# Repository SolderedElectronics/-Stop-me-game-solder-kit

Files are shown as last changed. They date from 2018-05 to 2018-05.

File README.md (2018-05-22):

# DIY_Stop_Me_Game_Kit

# Description and details
"Stop Me" game is small and simple game running on ATtiny13 microcontroller. It consists of 7 LEDs, push button, small CR2032 battery and microcontroller. The game starts with LEDs lightning up in sequential order. LED in the middle (4th in row) is different color in comparison to the rest of the LEDs. Goal of the game is very simple, player must press the push button when the middle LED (only one in different color) is light up. If the correct LED is turned on when the push button is pressed, the player goes on next level where time delay between LED lighting up is shortened. If any other LED is turned on when the push button is pressed, the game restarts to the first level. The game is designed to have multiple levels (12 in total). 

This game is designed as a DIY soldering kit. This kit is ideal for kids and soldering beginners who can exercise their skills with this simple & easy game. While learning to solder, you will also create unique gadget which you can carry around. In addition, while playing this simple game, players can exercise their reflex skills.

# Repository content

This repo is divided into two parts: Eagle Files and Firmware. Eagle Files folder contains Cadsoft Eagle .sch and .brd files for "Stop Me" game PCB board. in addition there is schematic in .pdf created from .sch eagle file. In Firmware folder you can find C code for programming ATtiny13 microcontroller. The entire program code uses less than 1kB of Flash memory.

# Instructions on soldering

1. Insert the 8 pin IC socket into IC. Flip the board over, then solder into place.
2. Insert the switch and pushbutton into S1 and S2. Flip the board over and solder into place.
3. Insert 7 LEDs into LED1, LED2, LED2, LED3, LED4, LED5, LED6. Each LED has a short leg and a long leg. The long leg goes into the hole closest to the "+" sign on the board. NOTE: The green LED goes into LED4 place. Flip the board over, then solder into place.
4. Flip the board over. Put CR2032 battery holder into BAT place. Don't put battery in holder just yet. Flip the board over again and solder into place. The battery holder is only piece which is soldered on the back side of PCB.
5. Insert Attiny13 microcontroller into 8 pin IC socket. Make sure the dot in the corner of the chip is on bottom left corner.
6. Insert CR2032 battery into soldered battery holder.
7. Yay you're done! Flip the switch to the ON position and the game should start. Have Fun playing it. 

# Board versions
- v1.0 - initial version

# License info
This product is open-source. YAY!

e-radionica.com Team.

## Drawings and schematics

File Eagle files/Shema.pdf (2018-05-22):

A

B

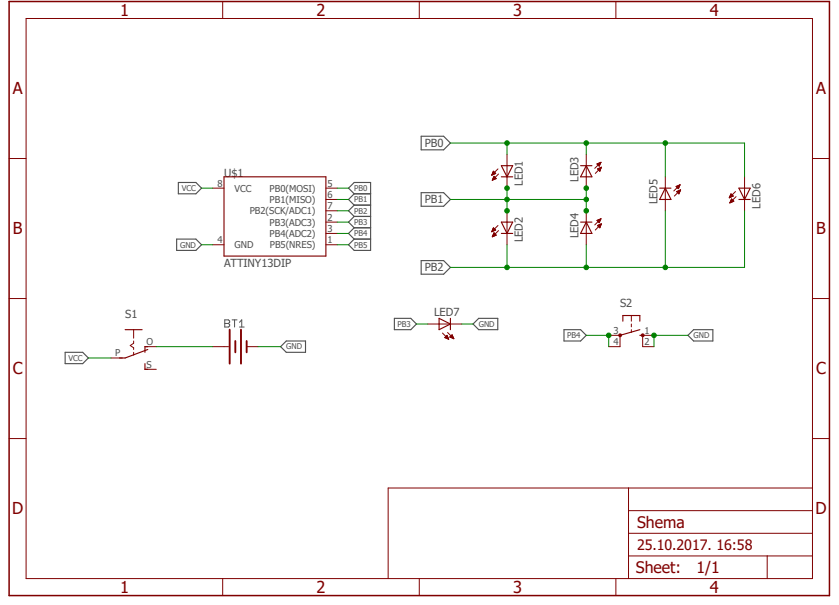
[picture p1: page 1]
ATTINY13DIP; U$1 VCC 8; PB1(MISO); PB5(NRES); 1 GND 4; PB0(MOSI); PB2(SCK/ADC1); PB3(ADC3); PB4(ADC2); LED¹ LED²; LED³ LED⁴; LED⁵; LED⁶; LED7; VCC; GND; Shema; 25.10.2017. 16:58 Sheet: 1/1

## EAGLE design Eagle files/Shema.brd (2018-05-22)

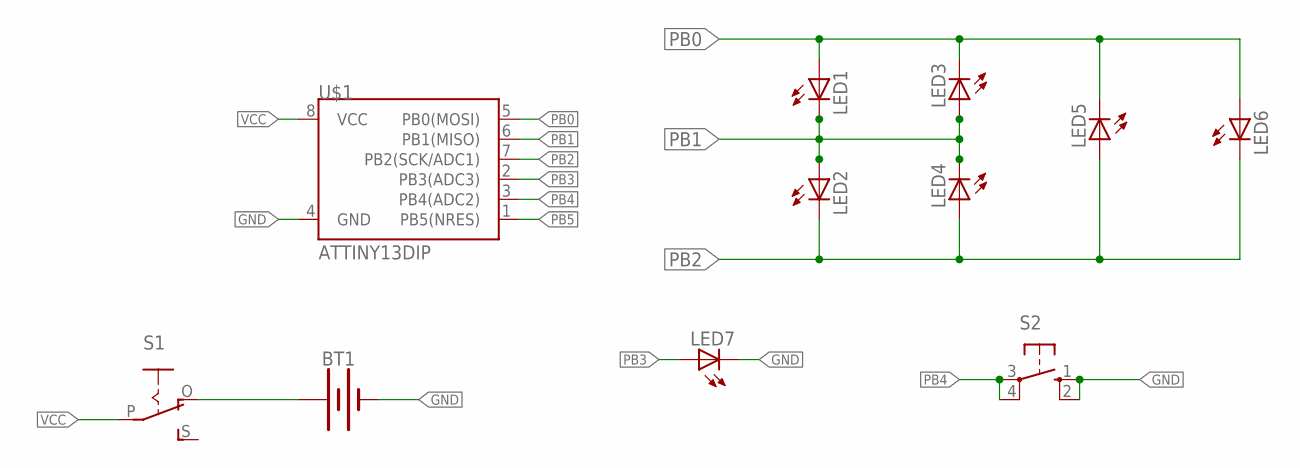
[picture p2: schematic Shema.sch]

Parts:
BT1: BATTERY-20MM_PTH; BATTCOM_20MM_PTH
LED1, LED2, LED3, LED4, LED5, LED6, LED7: LED5MM
S1: EG1218S; EG1218
S2: 40-XX; B3F-40XX
U$1: ATTINY13DIP; DIP08_MCU

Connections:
GND: BT1.2 (-), LED7.K (C), S2.1 (S), S2.2 (S1), U$1.4 (GND)
unnamed: BT1.1 (+), S1.O
PB0: LED1.A, LED3.K (C), LED5.K (C), LED6.A, U$1.5 (PB0(MOSI))
PB1: LED1.K (C), LED2.A, LED3.A, LED4.K (C), U$1.6 (PB1(MISO))
PB2: LED2.K (C), LED4.A, LED5.A, LED6.K (C), U$1.7 (PB2(SCK/ADC1))
PB3: LED7.A, U$1.2 (PB3(ADC3))
PB4: S2.3, S2.4 (P1), U$1.3 (PB4(ADC2))
PB5: U$1.1 (PB5(NRES))
VCC: S1.P, U$1.8 (VCC)

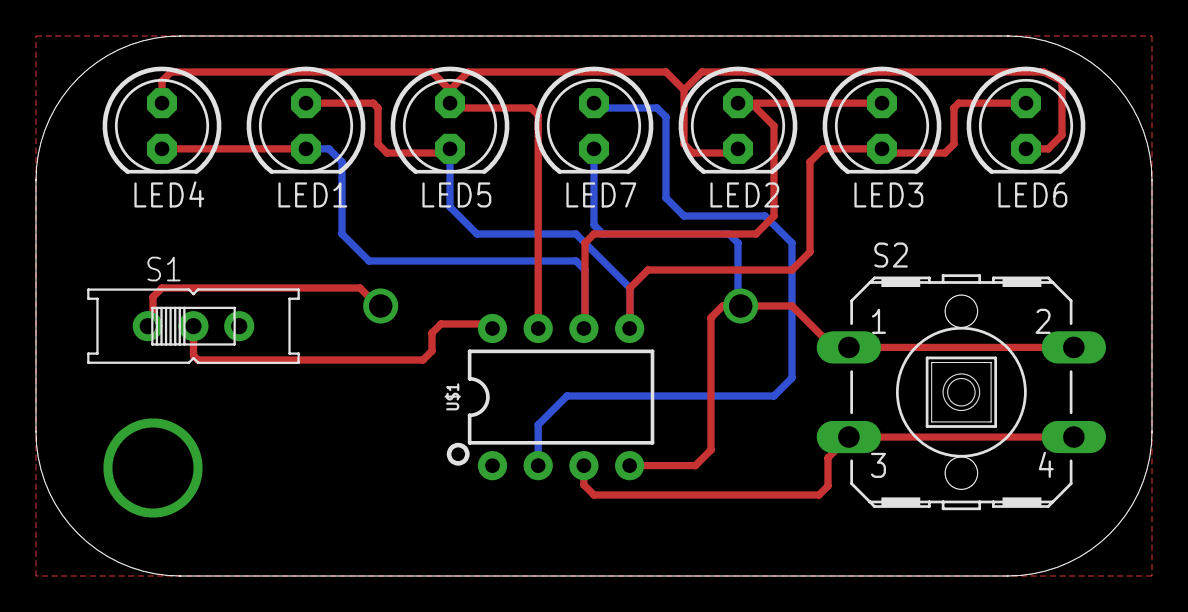
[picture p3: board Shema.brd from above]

Board: 2 copper layers, 62.0 x 30.0 mm, 11 parts (1 on the bottom side), 8 nets.

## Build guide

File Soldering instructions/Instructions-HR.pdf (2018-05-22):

### DIY „STOP ME“ IGRA

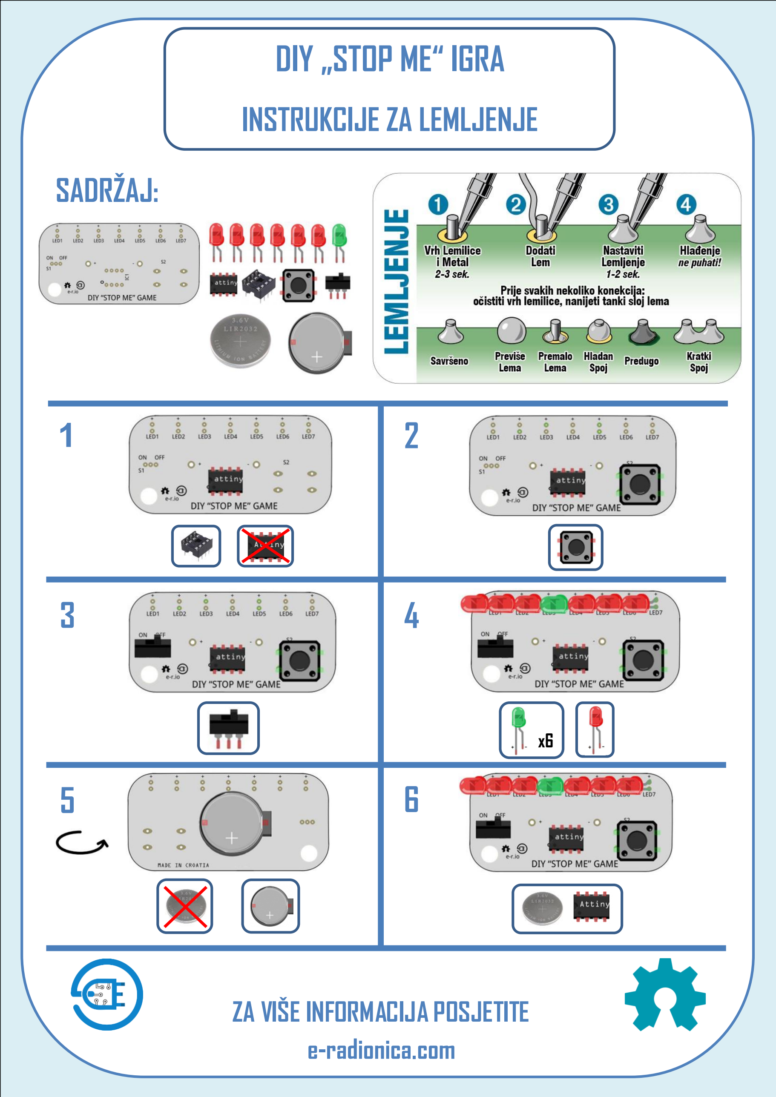
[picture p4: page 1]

ZA VIŠE INFORMACIJA POSJETITE e-radionica.com

INSTRUKCIJE ZA LEMLJENJE

SADRŽAJ:

6

1 2

3 4

5

x6

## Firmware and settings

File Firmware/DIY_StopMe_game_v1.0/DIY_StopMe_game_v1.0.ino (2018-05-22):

/*
 Project: "Stop me" LED game
 Version: 1.0
 Author: Domagoj Špoljar @ e-radionica.com
 Created: 17.09.2017
 Web: 

 Simple LED game where player must track which LED is blinking and
 press pushbutton when the green LED lights up.
 
 Features:
 -code optimised for attiny13a
 -uses less than 1KB of memory
 -12 different blinking speeds
 -powered by small CR2032 battery
 
 Arduino core for attiny85 - http://drazzy.com/package_drazzy.com_index.json 
 Arduino core for attiny13 - https://mcudude.github.io/MicroCore/package_MCUdude_MicroCore_index.json
*/

#include <avr/io.h>
#include <avr/interrupt.h>
//#include <util/delay.h>

#define F_CPU 1000000UL // 1Mhz CPU

volatile unsigned long millisec = 0;
volatile uint8_t previousReading  = 1; // holds last 8 pin reads from pushbutton
volatile uint8_t buttonWasPressed = 1; // keeps track of debounced button state, 0 false, 1 true
volatile uint8_t b_pressed = 0;
volatile uint8_t i = 0;                // counter variable

bool z = true;
unsigned long previousms = 0;
unsigned long ppreviousms = 0;
bool prijelaz = false;
int interval = 1000;
uint8_t br_blinkanja = 0;


void setLED(uint8_t LED)
{
  //Clear existing status, we can only drive one LED at a time
  PORTB &= 0xF0;    // Set the lower 3 bits to 0, i.e. off
  DDRB |= 0x07;   // Set the lower 3 bits to 1, i.e. output
  

  switch (LED)
  {
    case 1:
      DDRB  &= 0xFB;  // Disconnect the nr. 2 pin
      PORTB |= 0x01;  // Set pin 0 to high and pin 1 to low
      break;

    case 5:
      DDRB  &= 0xFB;  // Disconnect the nr. 2 pin
      PORTB |= 0x02;  // Set pin 1 to high and pin 0 to low
      break;

    case 4:
      DDRB  &= 0xFE;  // Disconnect the nr. 0 pin
      PORTB |= 0x02;  // Set pin 1 to high and pin 2 to low
      break;

    case 3:
      DDRB &= 0xF8; // Set pin 3 to output
      PORTB |= 0x08;  // Set pin 3 to high
      break;

    case 0:
      DDRB  &= 0xFE;  // Disconnect the nr. 0 pin
      PORTB |= 0x04;  // Set pin 2 to high and pin 1 to low
      break;

    case 6:
      DDRB  &= 0xFD;  // Disconnect the nr. 1 pin
      PORTB |= 0x01;  // Set pin 0 to high and pin 2 to low
      break;

    case 2:
      DDRB  &= 0xFD;  // Disconnect the nr. 1 pin
      PORTB |= 0x04;  // Set pin 2 to high and pin 0 to low
      break;

    default:
      break;
  }
}

static inline void initTimer0(void)         // timer0 is by default set to normal mode
{                                           // where it can count to 256 (FF) and then it overflows

  TCCR0B |= (_BV(CS02));                    // prescaler 256
  TIMSK0 |= (1 << OCIE0A) | (1 << OCIE0B);  // Enable CTC interrupt for OCR0A and OCR0B
  OCR0A = 3;                                // Set timer to compare 1 millisecond
  OCR0B = 122;                             // Set timer to compare 30 milliseconds
  sei();                                   // Enable global interrupts
}

ISR(TIM0_COMPA_vect) // when OCR0A gets a match (every 1ms) execute folowing...
{
  OCR0A += 2;  // used because of timer overflowing
  ++millisec; // add 1 to millisec variable which is used for measuring time
}

ISR(TIM0_COMPB_vect)
{
  OCR0B += 122;                                 //used because of timer overflowing
  if ((PINB & (1 << PB4)) != previousReading)   // if current button pin reading doesn't equal previousReading 30ms ago,
  {
    if (!buttonWasPressed)                    // and button wasn't pressed last time
    {
      if (i == 3) {                           // check which LED diode is on
        b_pressed = 1;                        // if LED 3 (green LED) is on 
      }
      else {                                  // if any other LED is on
        b_pressed = 2;
      }
      PORTB |= (1 << PB4);                    // keep pushbutton pull-up resistor on
      buttonWasPressed = 1;                   // set debounced button press state to 1
    }
    else
      buttonWasPressed = 0;                   // button has been let go, reset buttonWasPressed
  }
  previousReading = (PINB & (1 << PB4));      // set previous reading to current reading for next time
}



int main(void)
{

  DDRB = 0x0F;         // enable PB0-PB3 as an output
  PORTB |= (1 << PB4); // enable pullup on pushbutton output hooked up to PB4
  initTimer0();        // set up timer0

  while (1)            // loop
  {

    if (!prijelaz) {

      if (b_pressed != 0) {

        if (b_pressed == 1) {       // if the button is pressed when green LED is light up
                                    // make LEDs blink faster
          if (interval != 75) {
            if (interval <=125) interval = interval - 25 ;
            else if (interval <= 400) interval = interval - 50;
            else interval = interval - 125;
          }

        }
        else if (b_pressed == 2) {   //if the button is pressed when any of red LED is light up
          interval = 1000;            //reset LED blinking time to initial time
        };

        b_pressed = 0;
        prijelaz = true;
        ppreviousms = millisec;
      }

      else {

        setLED(i);

        if (millisec - previousms >= interval) {
          previousms = millisec;
          if (z) {
            i++;
            if (i == 6) {
              z = false;
            }
          }
          else {
            i--;
            if (i == 0) {
              z = true;
            }
          };
          
        };
      };
     // ppreviousms = millisec;
    }

    else {

      if (br_blinkanja < 5) {
        if (millisec - ppreviousms >= 400) {
          ppreviousms = millisec;
          if (br_blinkanja == 0 || br_blinkanja == 2 || br_blinkanja == 4) {
            PORTB &= 0xF0;    // Set the lower 3 bits to 0, i.e. off
            DDRB |= 0x07;   // Set the lower 3 bits to 1, i.e. output
            //PORTB |= (1 << PB4);
          }
          else {
            setLED(i);
          };

          br_blinkanja++;
        };

      }
      else {
        br_blinkanja = 0;
        prijelaz = false;
        b_pressed = 0;
        if (z) {
            i++;
            if (i == 6) {
              z = false;
            }
          }
          else {
            i--;
            if (i == 0) {
              z = true;
            }
          };
        
      };
      previousms = millisec;
    }
  }
}

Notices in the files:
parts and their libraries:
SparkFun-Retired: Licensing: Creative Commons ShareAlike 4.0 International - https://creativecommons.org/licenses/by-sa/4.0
